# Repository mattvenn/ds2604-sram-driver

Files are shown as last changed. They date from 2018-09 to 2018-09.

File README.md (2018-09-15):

# pinball high scores

Reading the high scores out of the SRAM of a pinball machine.

[inspiration](http://spritesmods.com/?art=twitter1943)

[Tweet thread
documentation](https://threadreaderapp.com/thread/1040240733838557184.html)

After modelling, testing and reading/writing to the SRAM. I only needed to
listen to the bus lines to know when the data was being read. That is done by
[addr_listener](hdl/addr_listener):

    always @(clk) begin
        if(sram_ce) begin
            if(ce_counter < WAIT)
                ce_counter <= ce_counter + 1;
            else if(ce_counter == WAIT) begin
                case(sram_address)
                    sc_100_k:
                        high_score[23:20] <= sram_data_pins[3:0];
                    sc_10_k:
                        high_score[19:16] <= sram_data_pins[3:0];
                    sc_1_k:
                        high_score[15:12] <= sram_data_pins[3:0];
                    sc_100:
                        high_score[11: 8] <= sram_data_pins[3:0];
                    sc_10:
                        high_score[ 7: 4] <= sram_data_pins[3:0];
                    sc_1:
                        high_score[ 3: 0] <= sram_data_pins[3:0];
                endcase
            end
        else
            ce_counter <= 0;
        end 
    end

## plan

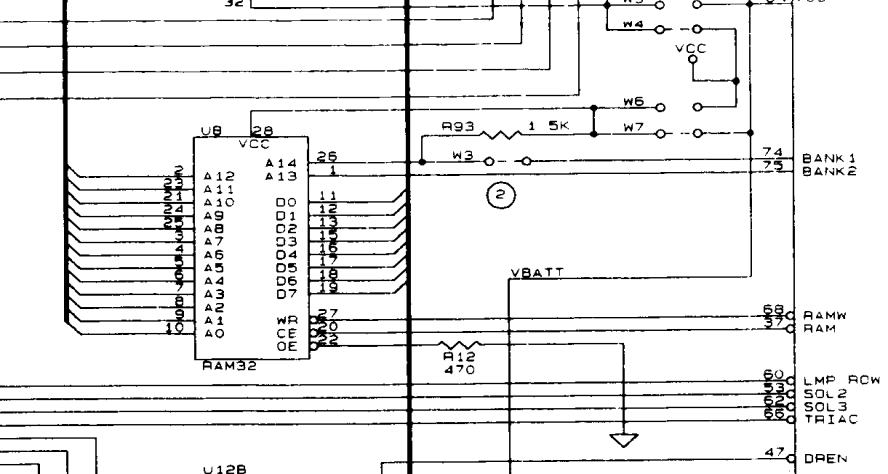
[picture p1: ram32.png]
ram32


* the ds2064 is socketed, so make a [breakout board](ram-fpga) that passes through the connections. 
* add an FPGA that can listen to the 13 address lines, the 8 data lines and the 3 read/write/select pins = 24pins.
* when in write mode, with address in the high score range the FPGA reads the data off the bus.
* write [ds2064 driver](hdl/sram_driver/README.md)

## board test

* data pins tx - ok
* data pins rx - ok - very high impedance!
* addr pins tx - ok
* addr pins rx - ok
* ctrl pins rx - ok
* ctrl pins tx - ok
* on programming fpga, 5v line draws up to 40mA
* added 10k resistor from tranceiver !oe to FPGA 3.3v to keep them off while being programmed

## functional test

* read and write work separately with python control
* however, a write followed by a read works with ram non connected!

# Resources

http://www.pinballsupernova.com/Williams%20Repair%20Guide/Williams%201990-1999%20WPC.pdf
page 20 ram details

emulator https://github.com/neophob/wpc-emu
http://bcd.github.io/freewpc/The-WPC-Hardware.html#The-WPC-Hardware

The CPU board contains the main processor: a Motorola 68B09E, running at 2Mhz. It is an 8-bit/16-bit CPU with a 64KB address space. Bank switching is required to address more than 64KB. On reset, location 0xFFFE is read to determine the address of the first instruction.

8KB of RAM is located at physical address 0x0000. When power is turned off, three AA batteries on the CPU board maintain the state of the RAM. 

## WPC89

fairly sure this is the main board on my doctor who pinball.
[good overview here](http://level42.ca/files/PinRepair/System%20WPC/WPC%20part1/index1.htm)

It uses a battery backed up [ds2064](docs/ds2064.pdf) to store audits and score I hope.

[Schematic](docs/wpc89.pdf)

# Available machines to try

## bride

https://www.ipdb.org/machine.cgi?gid=1502
williams wpc

## high speed

https://www.ipdb.org/machine.cgi?id=1176
Williams System 11

## grand lizard

https://www.ipdb.org/machine.cgi?id=1070
williams system 11

## fire power 

https://www.ipdb.org/machine.cgi?id=856
williams system 6  (rottendog MPU327-4)
good photo: https://pinside.com/pinball/market/classifieds/archive/25465

rottendog sram chip:
https://www.mouser.es/datasheet/2/12/AS6C6264A-1288481.pdf

initial high score is 550,000 = 0x00_g08_64_70 

couldn't find it, so got a fake new score: 803950 = 0x0c_44_6e
         = 80 39 50

         = 50 39 50

motorola 6800 is big endian, intel is little endian

After searching for packed BCD of default string - got a match at 0x1149

    grep -A3 '^1149' dump.8192.5
    1149 55
    114a 00
    114b 00
    114c 00

Then checked for the new high score that we set 803950:

    grep -A3 '^1149' dump.8000.newhigh
    1149 80
    114a 03
    114b 39
    114c 05

Write this to a default chip:

    ./control.py --port /dev/ttyUSB1 --addr-start 1149 --addr-end 114d --read --hex
    1149 80
    114a 03
    114b 39
    114c 05

And then read it back:

    ./control.py --port /dev/ttyUSB1 --addr-start 1149 --addr-end  114d --read --hex
    1149 80
    114a 03
    114b 39
    114c 05

But display shows 503950! Checked one byte before start address 1148:

    55 00 00:
    1148 05
    1149 55
    114a 00
    114b 00
    114c 00

    80 39 50:
    1148 08
    1149 80
    114a 03
    114b 39
    114c 05

And can see it's the low nibble in each byte. Don't know what the upper nibble
represents. Wrote 10k to the score and it works, can beat it easily - which
should make the next step easier.

wrote 10k with:

    ./control.py --port /dev/ttyUSB1 --addr-start 1148 --addr-end  114d --write --hex --value 0001000000

only lower half of the byte

    1148 : 100ks
    1149 : 10ks
    114a : 1ks
    114b : 100's
    114c : 10's
    114d : 1's

so a write to 1149 is the 10k number.

## doctor who

https://www.ipdb.org/machine.cgi?id=738
williams wpc (fliptronics2)

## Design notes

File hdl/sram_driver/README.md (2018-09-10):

# sram driver

drives an 8k x 8bit SRAM chip like the ds2064

    input wire             clk,                 // expecting 12Mhz, adjust WAIT_TIME if this changes
    input wire             reset,               // reset high

    // module control
    input wire             re,                  // read enable, otherwise write
    input wire             start,               // start a transaction
    output reg             ready,               // assert high when ready for a new transaction
    input  wire [12:0]     address,             // input address
    input  wire [7:0]      data_in,             // data to write here
    output reg [7:0]       data_out,            // data read is here

    // memory control
    output reg [12:0]      sram_address,        // sram address
    output reg [7:0]       sram_data_write,     // sram data pins out
    input  wire [7:0]      sram_data_read,      // sram data pins in
    output reg             sram_data_pins_oe,   // sram data pins direction, high for data out
    output wire            n_ce1,               // !ce1
    output wire            ce2,                 // ce2 - combination of these chip enables standby
    output wire            n_we,                // !we - low to write
    output wire            n_oe                 // !oe - low to enable outputs
    );

    parameter WAIT_TIME = 2;                    // parameter to set how long to wait before a read or write is done

# test bench

uses model of ds2064 with semi accurate timings for reads and writes

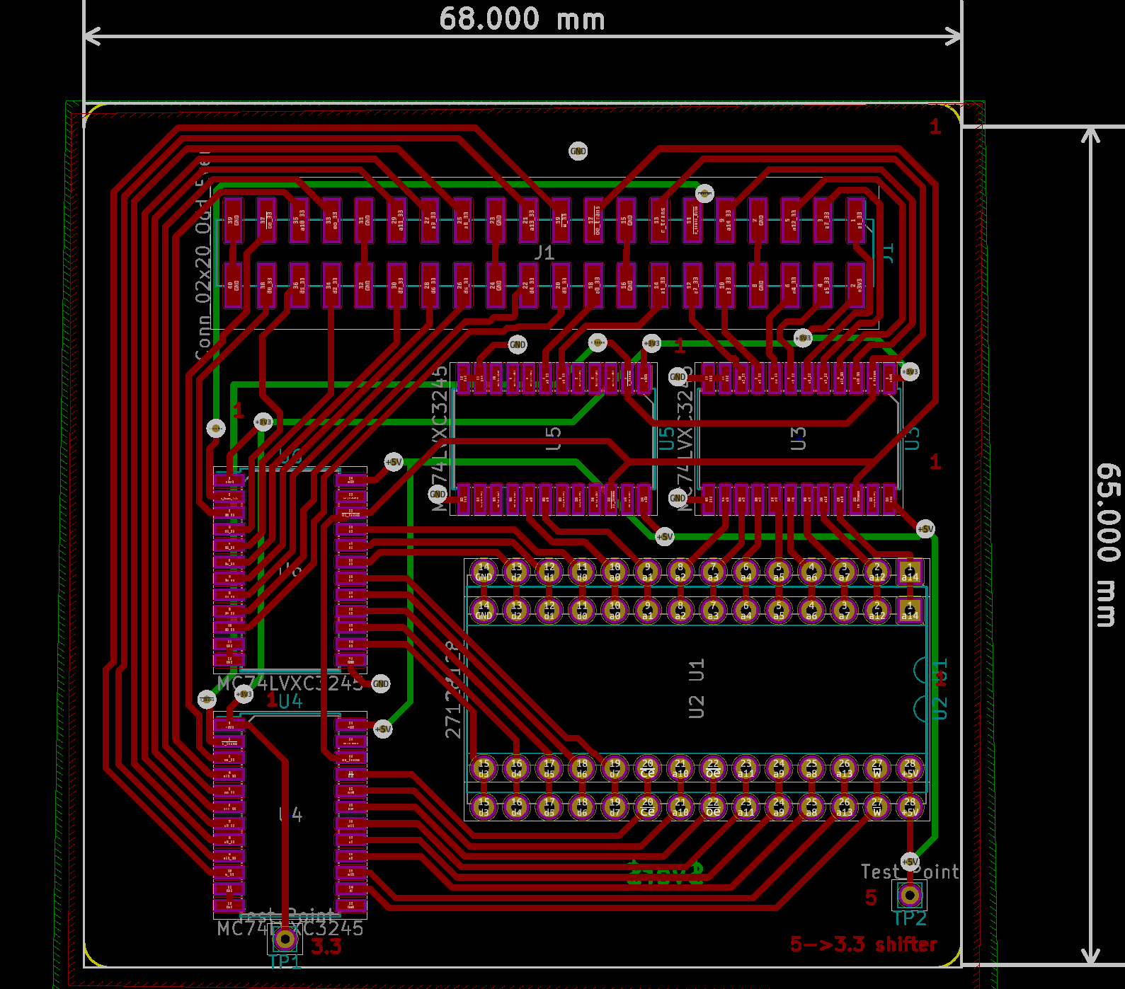
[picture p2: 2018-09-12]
docs/board.png

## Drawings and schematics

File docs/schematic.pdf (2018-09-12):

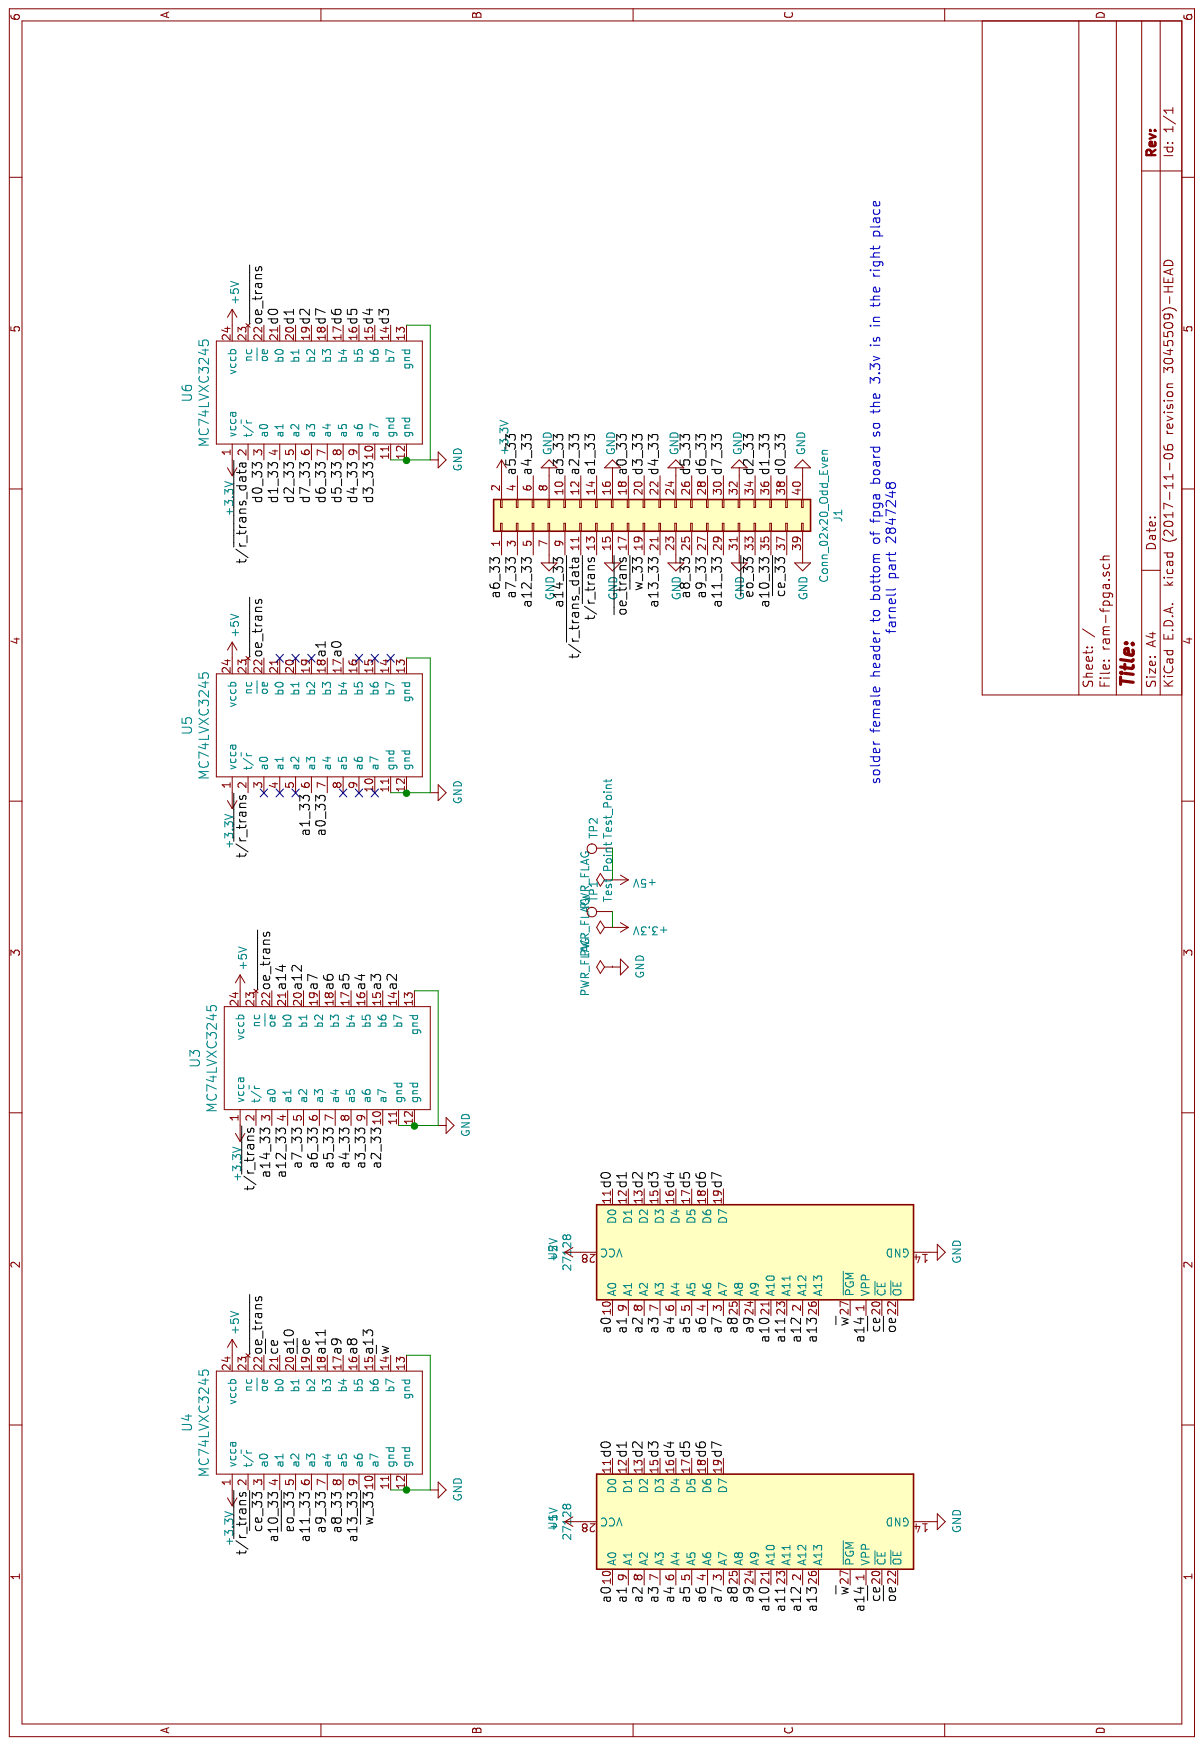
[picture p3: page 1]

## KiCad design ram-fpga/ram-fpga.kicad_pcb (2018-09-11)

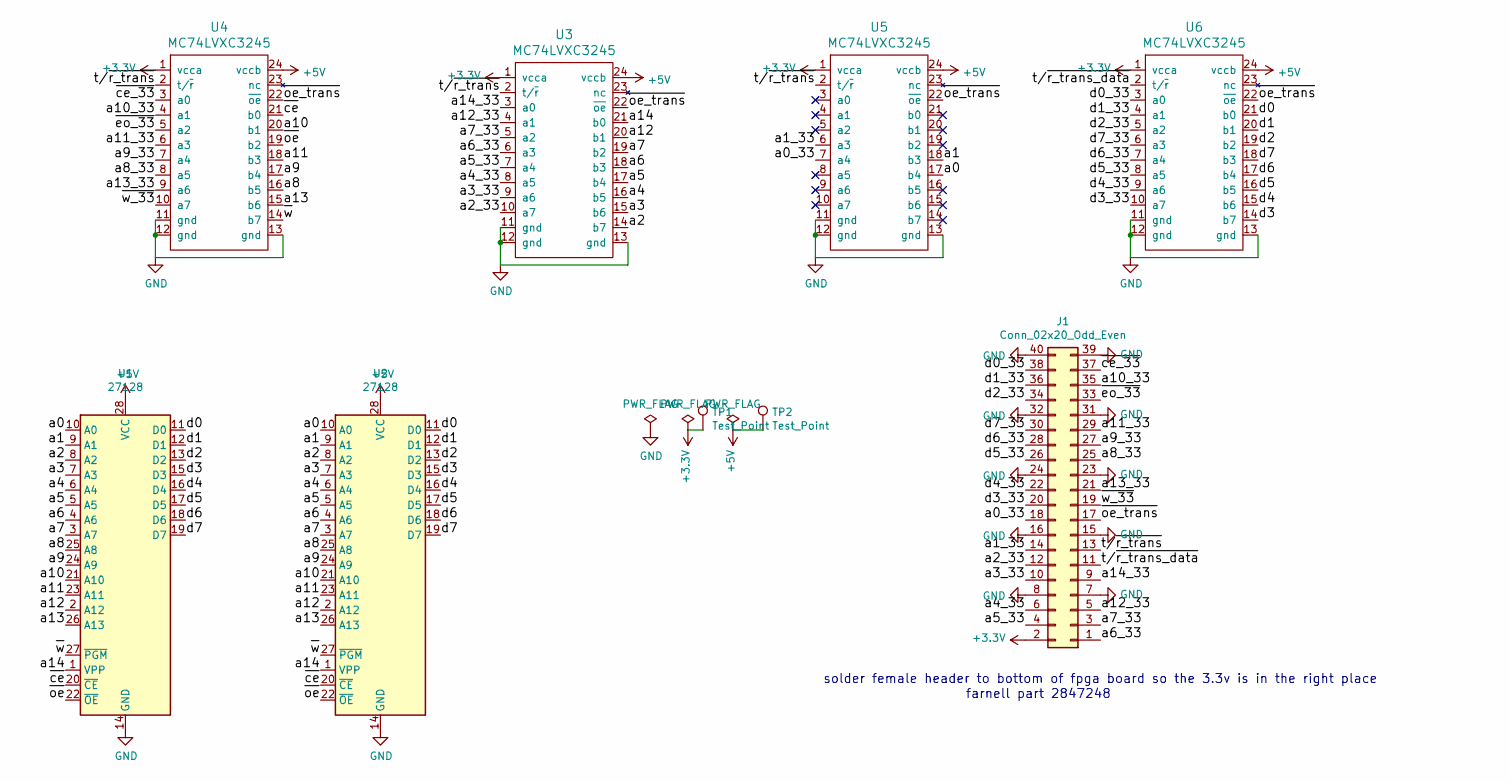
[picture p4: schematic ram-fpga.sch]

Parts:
J1: Conn_02x20_Odd_Even; PinHeader_2x20_P2.54mm_Vertical_SMD
TP1, TP2: Test_Point; Pin_D0.7mm_L6.5mm_W1.8mm_FlatFork
U1, U2: 27128; DIP-28_W15.24mm
U3, U4, U5, U6: MC74LVXC3245; SOIC-24W_7.5x15.4mm_P1.27mm; farnell # 2630416

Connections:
+3V3: J1.2, TP1.1, U3.1 (vcca), U4.1 (vcca), U5.1 (vcca), U6.1 (vcca)
+5V: TP2.1, U1.28 (VCC), U2.28 (VCC), U3.24 (vccb), U4.24 (vccb), U5.24 (vccb), U6.24 (vccb)
/a0: U1.10 (A0), U2.10 (A0), U5.17 (b4)
/a0_33: J1.18, U5.7 (a4)
/a1: U1.9 (A1), U2.9 (A1), U5.18 (b3)
/a1_33: J1.14, U5.6 (a3)
/a2: U1.8 (A2), U2.8 (A2), U3.14 (b7)
/a2_33: J1.12, U3.10 (a7)
/a3: U1.7 (A3), U2.7 (A3), U3.15 (b6)
/a3_33: J1.10, U3.9 (a6)
/a4: U1.6 (A4), U2.6 (A4), U3.16 (b5)
/a4_33: J1.6, U3.8 (a5)
/a5: U1.5 (A5), U2.5 (A5), U3.17 (b4)
/a5_33: J1.4, U3.7 (a4)
/a6: U1.4 (A6), U2.4 (A6), U3.18 (b3)
/a6_33: J1.1, U3.6 (a3)
/a7: U1.3 (A7), U2.3 (A7), U3.19 (b2)
/a7_33: J1.3, U3.5 (a2)
/a8: U1.25 (A8), U2.25 (A8), U4.16 (b5)
/a8_33: J1.25, U4.8 (a5)
/a9: U1.24 (A9), U2.24 (A9), U4.17 (b4)
/a9_33: J1.27, U4.7 (a4)
/a10: U1.21 (A10), U2.21 (A10), U4.20 (b1)
/a10_33: J1.35, U4.4 (a1)
/a11: U1.23 (A11), U2.23 (A11), U4.18 (b3)
/a11_33: J1.29, U4.6 (a3)
/a12: U1.2 (A12), U2.2 (A12), U3.20 (b1)
/a12_33: J1.5, U3.4 (a1)
/a13: U1.26 (A13), U2.26 (A13), U4.15 (b6)
/a13_33: J1.21, U4.9 (a6)
/a14: U1.1 (VPP), U2.1 (VPP), U3.21 (b0)
/a14_33: J1.9, U3.3 (a0)
/d0: U1.11 (D0), U2.11 (D0), U6.21 (b0)
/d0_33: J1.38, U6.3 (a0)
/d1: U1.12 (D1), U2.12 (D1), U6.20 (b1)
/d1_33: J1.36, U6.4 (a1)
/d2: U1.13 (D2), U2.13 (D2), U6.19 (b2)
/d2_33: J1.34, U6.5 (a2)
/d3: U1.15 (D3), U2.15 (D3), U6.14 (b7)
/d3_33: J1.20, U6.10 (a7)
/d4: U1.16 (D4), U2.16 (D4), U6.15 (b6)
/d4_33: J1.22, U6.9 (a6)
/d5: U1.17 (D5), U2.17 (D5), U6.16 (b5)
/d5_33: J1.26, U6.8 (a5)
/d6: U1.18 (D6), U2.18 (D6), U6.17 (b4)
/d6_33: J1.28, U6.7 (a4)
/d7: U1.19 (D7), U2.19 (D7), U6.18 (b3)
/d7_33: J1.30, U6.6 (a3)
/t/~r_trans: J1.13, U3.2 (t/~r), U4.2 (t/~r), U5.2 (t/~r)
/t/~r_trans_data: J1.11, U6.2 (t/~r)
/~ce: U1.20 (~CE), U2.20 (~CE), U4.21 (b0)
/~ce_33: J1.37, U4.3 (a0)
/~eo_33: J1.33, U4.5 (a2)
/~oe: U1.22 (~OE), U2.22 (~OE), U4.19 (b2)
/~oe_trans: J1.17, U3.22 (~oe), U4.22 (~oe), U5.22 (~oe), U6.22 (~oe)
/~w: U1.27 (~PGM), U2.27 (~PGM), U4.14 (b7)
/~w_33: J1.19, U4.10 (a7)
GND: J1.7, J1.8, J1.15, J1.16, J1.23, J1.24, J1.31, J1.32, J1.39, J1.40, U1.14 (GND), U2.14 (GND), U3.11 (gnd), U3.12 (gnd), U3.13 (gnd), U4.11 (gnd), U4.12 (gnd), U4.13 (gnd), U5.11 (gnd), U5.12 (gnd), U5.13 (gnd), U6.11 (gnd), U6.12 (gnd), U6.13 (gnd)

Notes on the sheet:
solder female header to bottom of fpga board so the 3.3v is in the right place
farnell part 2847248

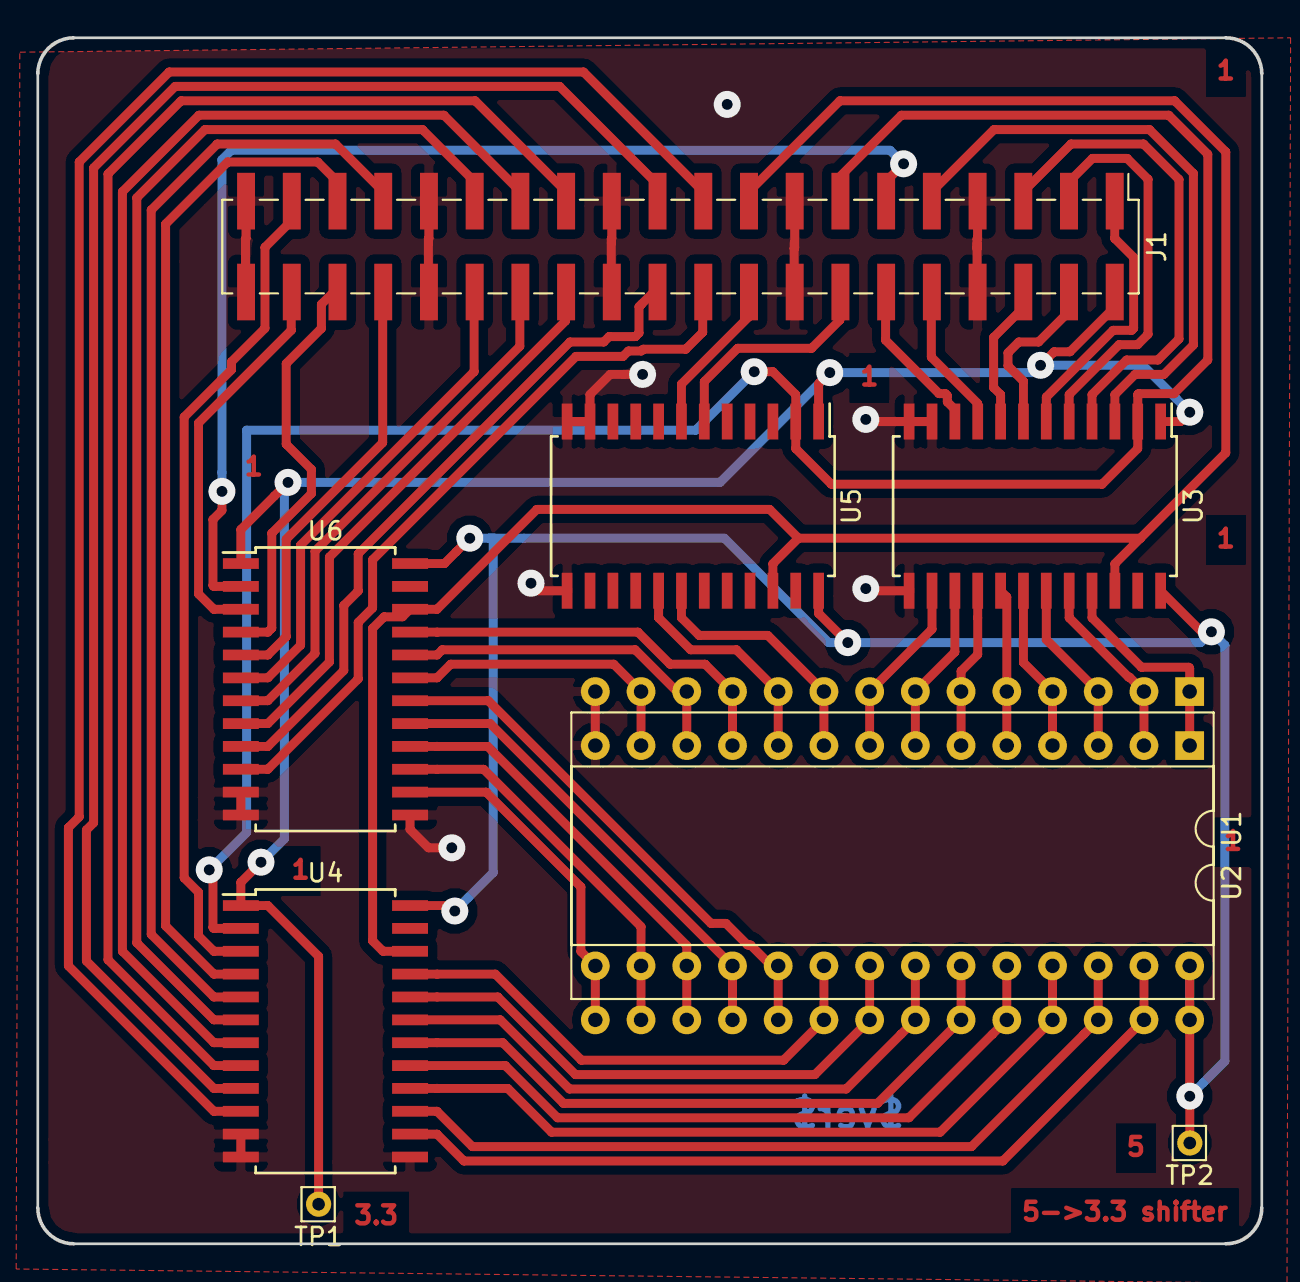
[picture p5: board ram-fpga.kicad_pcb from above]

Board: 2 copper layers, 68.0 x 67.0 mm, 9 parts (0 on the bottom side), 58 nets.

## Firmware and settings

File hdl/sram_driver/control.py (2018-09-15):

#!/usr/bin/python
import argparse
import serial
import csv
import struct
import time
import random


cmds = { 
    'ADDR' : 1 ,
    'LOAD' : 2,
    'WRITE' : 3,
    'READ' : 4,
    'READ_REQ' : 5,
    'COUNT': 6,
    'SCORE': 7,
    }

def cmd(cmd, tx_data=0):
    ser.write(struct.pack('B', cmds[cmd] ))
    ser.write(struct.pack('>I', tx_data))

    rx_data = ser.read(4)
    data, = struct.unpack('>I', rx_data)
    if args.verbose:
        print(cmd, tx_data, data)
    return data


if __name__ == '__main__':
    parser = argparse.ArgumentParser(description="communicate with FPGA over serial")
    parser.add_argument('--score', const=True, action="store_const", help="read high score")
    parser.add_argument('--port', default='/dev/ttyUSB1', help="serial port")
    parser.add_argument('--write', const=True, action="store_const", help="write test")
    parser.add_argument('--read', const=True, action="store_const", help="read test")
    parser.add_argument('--sequential', const=True, action="store_const", help="sequential write")
    parser.add_argument('--random', const=True, action="store_const", help="random write")
    parser.add_argument('--addr-end', default="10", help="number to end")
    parser.add_argument('--addr-start', default="0", help="where to start")
    parser.add_argument('-v','--verbose', dest="verbose", action="store_const", help="verbose", const=True)
    parser.add_argument('--hex', dest="hex", action="store_const", help="output in hex", const=True)
    parser.add_argument('--value', help="what value to write")

    args = parser.parse_args()

    ser=serial.Serial()
    ser.port=args.port
    ser.baudrate=115200
    ser.timeout=1
    ser.open()

    # if hex is given, assume addr args also in hex
    base = 10
    if args.hex:
        base = 16
    args.addr_end = int(args.addr_end, base)
    args.addr_start = int(args.addr_start, base)

    if args.write and args.value:
    # check right length
        if len(args.value) / 2 != args.addr_end - args.addr_start:
            exit("value is unexpected length %d - should be %d" % (len(args.value) / 2, args.addr_end - args.addr_start))

    if args.score:
        data = cmd('SCORE')
        score = int(hex(data).replace('0x', ''))
        print("high score: %d" % score)
        exit()

    index = 0
    try:
        for addr in range(args.addr_start, args.addr_end):

            if args.sequential:
                number = addr % 255
            elif args.random:
                number = random.randint(0,255)
            elif args.value:
                byte = args.value[index:index+2]
                number = int(byte,16)
                index += 2
            else:
                if args.write:
                    exit("must give sequential or random argument")

            data = cmd('ADDR', addr)
            if args.write:
                cmd('LOAD', number)
                cmd('WRITE')
                if args.hex:
                    print("%04x %02x" % (addr, number))
                else:
                    print("%d %d" % (addr, number))
            if args.read:
                cmd('READ_REQ')
                read_data = cmd('READ')
                if args.hex:
                    print("%04x %02x" % (addr, read_data))
                else:
                    print("%d %d" % (addr, read_data))

            if args.read and args.write:
                if(read_data == number):
                    pass
                else:
                    print("failed at addr %d, was %d" % (addr, read_data))

    except KeyboardInterrupt as e:
        print("quitting")
        print(addr)

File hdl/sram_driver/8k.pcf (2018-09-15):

###################################
# Physical constraints file (pcf) #
# for iCE40HX8K-CT256             #
###################################


### Clock
set_io --warn-no-port clk J3

### LEDs
set_io --warn-no-port LED[0] B5
set_io --warn-no-port LED[1] B4
set_io --warn-no-port LED[2] A2
set_io --warn-no-port LED[3] A1
set_io --warn-no-port LED[4] C5
set_io --warn-no-port LED[5] C4
set_io --warn-no-port LED[6] B3
set_io --warn-no-port LED[7] C3


### UART (FTDI Channel B)
set_io --warn-no-port rx B10
set_io --warn-no-port tx B12
set_io --warn-no-port RTSn       B13
set_io --warn-no-port CTSn       A15
set_io --warn-no-port dtr       A16
set_io --warn-no-port DSRn       B14
set_io --warn-no-port DCDn       B15

#				 J3
#			       --------
#			 1---| R16 VCC |---2	VCCIO2
#       	 3---| T15 T16 |---4
#			 5---| T13 T14 |---6
#			 7---| GND GND |---8
#			 9---| N12 P13 |---10
#			     --------
#			11---| N10 M11 |---12
#			13---| T11 P10 |---14
#			15---| GND GND |---16
#			17---| T10 R10 |---18
#			19---| P8  P9  |---20
#			      --------
#			21---| T9  R9  |---22
#			23---| GND GND |---24
#			25---| T7  T8  |---26
#			27---| T6  R6  |---28
#			29---| T5  R5  |---30
#			      --------
#			31---| GND GND |---32
#			33---| R3  R4  |---34
#			35---| R2  T3  |---36
#			37---| T1  T2  |---38
#			39---| GND GND |---40
#			      ---------

# sram control pins
set_io --warn-no-port sram_ce2      T9 # was addr13, on this sram is cs2
set_io --warn-no-port sram_n_oe     R3 # eeprom !oe - always tied to gnd
set_io --warn-no-port sram_n_ce1    T1 # eeprom !cs1
set_io --warn-no-port sram_n_write  P8  # sram n_write pin


set_io --warn-no-port trans_n_oe T10 # !oe all tranceivers
set_io --warn-no-port trans_tx_data N10 # transceiver tx !rx data
set_io --warn-no-port trans_tx_sram_address T11 # transceiver tx !rx address and ctrl
set_io --warn-no-port sram_address[0]  R10
set_io --warn-no-port sram_address[1]  P10
set_io --warn-no-port sram_address[2]  M11
set_io --warn-no-port sram_address[3]  P13
set_io --warn-no-port sram_address[4]  T14
set_io --warn-no-port sram_address[5]  T16
set_io --warn-no-port sram_address[6]  R16
set_io --warn-no-port sram_address[7]  T15
set_io --warn-no-port sram_address[8]  T7
set_io --warn-no-port sram_address[9]  T6
set_io --warn-no-port sram_address[10] R2
set_io --warn-no-port sram_address[11] T5
set_io --warn-no-port sram_address[12] T13

#set_io --warn-no-port sram_address[14] N12

set_io --warn-no-port sram_data_pins[0]  T2
set_io --warn-no-port sram_data_pins[1]  T3
set_io --warn-no-port sram_data_pins[2]  R4
set_io --warn-no-port sram_data_pins[3]  P9
set_io --warn-no-port sram_data_pins[4]  R9
set_io --warn-no-port sram_data_pins[5]  T8
set_io --warn-no-port sram_data_pins[6]  R6
set_io --warn-no-port sram_data_pins[7]  R5

#set_io --warn-no-port sram_data_write[3]  P9
#set_io --warn-no-port sram_data_write[4]  R9
#set_io --warn-no-port sram_data_write[5]  T8
#set_io --warn-no-port sram_data_write[6]  R6
#set_io --warn-no-port sram_data_write[7]  R5
#set_io --warn-no-port sram_data_write[2]  R4
#set_io --warn-no-port sram_data_write[1]  T3
#set_io --warn-no-port sram_data_write[0]  T2

#set_io --warn-no-port sram_data_read[3]  P9
#set_io --warn-no-port sram_data_read[4]  R9
#set_io --warn-no-port sram_data_read[5]  T8
#set_io --warn-no-port sram_data_read[6]  R6
#set_io --warn-no-port sram_data_read[7]  R5
#set_io --warn-no-port sram_data_read[2]  R4
#set_io --warn-no-port sram_data_read[1]  T3
#set_io --warn-no-port sram_data_read[0]  T2


# ----------------------------- BANK-1 --------------------------------------------------------


# ------------------------ PMOD1 connector (J2)------------------------------------------------
#
#
#                     ************************************
#                     *                                  *
# --------------------*-INSTALADO DE FABRICA EN LA PLACA *------------------------------------- 
#                     *                                  *
#                     ************************************
#
#
#
#				 J2
#			       --------
#			 1---| 1V2 VCC |---2	VCCIO1_01
#     			 3---| 1V2 R15 |---4
#			 5---| P16 P15 |---6
#			 7---| GND GND |---8
#			 9---| N16 M15 |---10
#			     --------
#			11---| M16 L16 |---12
#			13---| K15 K16 |---14
#			15---| GND GND |---16
#			17---| K14 J14 |---18
#			19---| G14 F14 |---20
#			      --------
#			21---| J15 H14 |---22
#			23---| GND GND |---24
#		GBIN2	25---| H16 G15 |---26
#			27---| G16 F15 |---28
#			29---| F16 E14 |---30
#			      --------
#			31---| GND GND |---32
#			33---| E16 D15 |---34
#			35---| D16 D14 |---36
#			37---| C16 B16 |---38
#			39---| GND GND |---40
#			      ---------
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

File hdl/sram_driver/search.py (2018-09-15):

#!/usr/bin/python
import argparse
from pprint import pprint

if __name__ == '__main__':
    parser = argparse.ArgumentParser(description="search for BCD patterns in data")
    parser.add_argument('--dumpfile', help="dumpfile", required=True)
    parser.add_argument('--score', help="number to search", required=True)

    args = parser.parse_args()

    print("looking for %s in %s" % (args.score, args.dumpfile))

    with open(args.dumpfile) as fh:
        lines = fh.readlines()

    print("read %d lines" % len(lines))

    index = 0
    save_lines = []
    found = False
    for line in lines:
        # interested in the last digit only
        digit = line[6]

        if digit == args.score[index]:
            save_lines.append(line)
            index += 1
            found = True
        elif found == True:
            found = False
            index = 0
            save_lines = []

        if index == len(args.score):
            print("done")
            pprint(save_lines)
            exit(0)

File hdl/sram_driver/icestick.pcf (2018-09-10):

set_io LED 95 # centre green
set_io clk 21

#  44   - -  45
#  62  |   | 47
#  119  - -  118
#  61  |   | 48
#  60   - -  56
#      
        
set_io sram_data_pins[7] 47
set_io sram_data_pins[6] 48
set_io sram_data_pins[5] 56
set_io sram_data_pins[4] 60
set_io sram_data_pins[3] 61
set_io sram_data_pins[2] 62
set_io sram_data_pins[1] 119
set_io sram_data_pins[0] 118

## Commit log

2018-09-11 switch to smt header
    [ram-fpga.kicad_pcb, ram-fpga.sch]
2018-09-12 print number
2018-09-12 readme and changed orientation of schematic
    [ram-fpga.sch]
2018-09-12 schematic pdf & board png
2018-09-12 note about 10k pullup
    [ram-fpga.sch]
2018-09-13 state filters for gtkw
2018-09-13 appears to be working - need to check if still has data stuck bug
    [control.py]
2018-09-13 remove a bit of print debugging
2018-09-14 read mode board test
2018-09-15 listens for address reads at the high score location and shows on leds
